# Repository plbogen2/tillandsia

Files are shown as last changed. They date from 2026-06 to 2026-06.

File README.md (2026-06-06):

# Aeropress Cleaners (ADCR & AMFC)

This repository contains two 3D-printable, office-desk-friendly cleaning tools for the **AeroPress** coffee maker, designed to clean coffee grounds directly over a trash can:
1.  **Plunger Wiper Ring (ADCR)**: Sweeps coffee grounds off the rubber plunger seal face using a spring-returned pivoted squeegee.
2.  **Metal Filter Cleaner (AMFC)**: Wipes grounds off both sides of a circular metal mesh filter using a clamped double-sided squeegee envelope.

Both tools are designed to print completely **support-free** and assemble using standard Prusa-style **M3 metal screws** and a **harvested Mounjaro pen spring**.

---

## 1. Plunger Wiper Ring (ADCR)

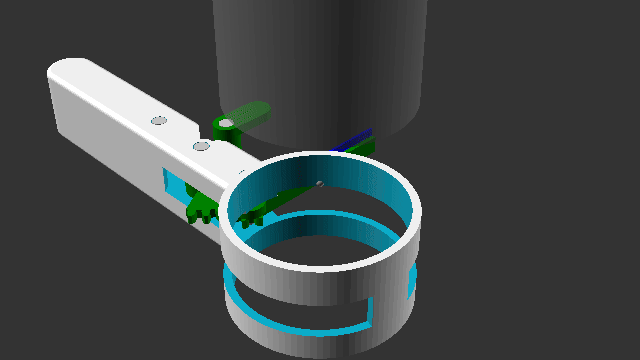
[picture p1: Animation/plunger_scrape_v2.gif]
Plunger Scraping Action


### How It Works:
*   Slide the ring collar over the Aeropress plunger seal until it sits flush against the internal stop ledge.
*   Push the thumb lever to compress the spring and sweep the flexible blade across the plunger face.
*   Release the lever. The vertical Mounjaro pen spring pops the arm back to the park position.
*   Coffee grounds fall out the open bottom of the ring.

### Bill of Materials & Print Guide:
*   **M3x12mm Screw** (x1): Functions as the metal hinge pivot shaft. Threads directly into the top knuckle plastic.
*   **Mounjaro Pen Spring** (x1): Harvested from a spent injection pen (approx. 8mm OD, 40mm length).
*   **ring.stl** (Rigid): Print **upside-down (top rim on bed)**, no supports.
*   **wiper.stl** (Rigid): Print flat on bed.
*   **blade.stl** (Flexible TPU): Print flat on bed.

---

## 2. Metal Filter Cleaner (AMFC)

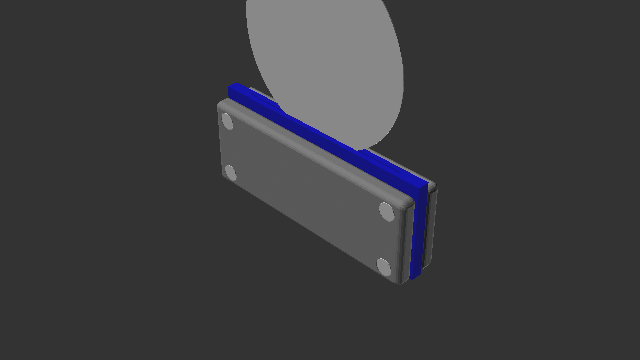
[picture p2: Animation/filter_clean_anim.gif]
Filter Cleaning Action


### How It Works:
*   Hold the filter cleaner vertically over a trash can.
*   Push your circular metal mesh filter ($62\text{mm}$) down into the top chamfered funnel guide.
*   Slide the filter all the way through the channel. Dual TPU squeegee blades scrape both faces of the filter at the same time.
*   Cleaned filter slides out the bottom, while grounds fall straight down into the trash.

### Bill of Materials & Print Guide:
*   **M3x12mm Screws** (x4): Securely clamp the front and back halves together.
*   **filter_front.stl** (Rigid): Contains M3 clearance screw holes. Print flat, mating face on bed.
*   **filter_back.stl** (Rigid): Contains M3 tap holes. Print flat, mating face on bed.
*   **filter_blade.stl** (Flexible TPU, x2): Print flat. Simple rectangular squeegee sheets ($55\text{mm} \times 15\text{mm} \times 1.5\text{mm}$).

---

## Assembly Instructions

### Plunger Ring:
1.  Insert the flexible **blade** into the slot on the **wiper** arm (starts 8mm from pivot).
2.  Press-fit the Mounjaro pen spring onto the stationary **Ring Post peg** and the moving **Lever Post peg**.
3.  Align the wiper knuckle with the ring knuckles and insert your **M3x12mm screw** from the bottom. Tighten until the head is flush inside the bottom recess.

### Filter Cleaner:
1.  Place the two flat TPU **filter_blade** sheets into the recesses of the **filter_front** and **filter_back** halves.
2.  Press the front and back halves together (alignment tracks will match).
3.  Insert **four M3x12mm screws** from the front clearance side and screw them securely into the back tap holes to clamp the blades flat.

---

## Customization in OpenSCAD
Each project has its own parametric model:
*   `aeropress_cleaner.scad`: Customizable plunger diameters (`plunger_di`), wall thickness, and M3 clearance fits.
*   `filter_cleaner.scad`: Customizable filter diameters (`filter_di`), filter thickness, and blade clearances.

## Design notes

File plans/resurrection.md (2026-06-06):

# Jetski Project Resurrection State: Aeropress Cleaners (ADCR & AMFC)

Use this file to instantly restore context, design knowledge, and execution progress when starting a new session or switching development machines.

---

## 1. Project Goals
Design and print support-free, office-desk-friendly cleaning tools for the **AeroPress** coffee maker:
1.  **Plunger Wiper Ring (ADCR)**: Cleans the rubber plunger seal face (diameter **57.2mm**, dome: **3.5mm**) using a spring-returned pivoted squeegee. Uses a harvested Mounjaro pen spring and a single M3x12mm screw.
2.  **Metal Filter Cleaner (AMFC)**: Wipes grounds off both sides of a circular metal mesh filter (diameter **62.0mm**, thickness **0.3mm**) using a clamped double-sided squeegee envelope. Uses four M3x12mm screws.

---

## 2. Selected Architectures

### Plunger Wiper Ring (ADCR)
*   **Ring Body (Rigid)**: A 35mm tall collar (ID 57.5mm) with an internal stop ledge (ID 53.0mm) at $z = 15.0 \to 18.0\text{ mm}$ and a $10.0\text{ mm}$ tall wall slot ($z = -8.0 \to +2.0\text{ mm}$) covering $330^\circ$.
*   **Clevis Hinge**: Double shear knuckles at $z = -12.0 \to -8.0\text{ mm}$ (lower) and $z = -4.0 \to 0.0\text{ mm}$ (upper). Secures via an M3x12mm screw.
*   **Wiper Arm & Blade**: A $65\text{mm}$ lever with a $57\text{mm}$ TPU blade starting at local $x = 8.0\text{ mm}$ to clear the hinge.
*   **Spring Return**: Mounjaro pen spring captured vertically on $6\text{mm}$ pegs on the ring post and lever post.

### Metal Filter Cleaner (AMFC)
*   **Front Half (Rigid)**: Contains a recessed track (depth $0.5\text{mm}$, width $62.5\text{mm}$) for the filter path, a pocket ($55.2\text{mm} \times 15.2\text{mm} \times 1.5\text{mm}$) for one TPU blade, and four M3 screw clearance holes (diameter $3.3\text{mm}$) with countersunk recesses.
*   **Back Half (Rigid)**: Mirrored copy of the front half, but with M3 tap holes (diameter $2.8\text{mm}$) to screw the clamp halves together.
*   **Wiper Blades (Flexible TPU, x2)**: Flat rectangular sheets ($55.0\text{mm} \times 15.0\text{mm} \times 1.5\text{mm}$) clamped between the halves, with tips extending into the channel to scrape both sides of the filter mesh.

---

## 3. Parametric Design Values

### Plunger Ring (`aeropress_cleaner.scad`)
*   `plunger_di = 57.2;` (AeroPress plunger seal diameter)
*   `wall_thickness = 3.0;` (Ring shell thickness)
*   `pivot_x = -35.0; pivot_y = 0.0;` (Pivot position)
*   `screw_tap_d = 2.8;` (Upper knuckle tap bore for M3 screw)
*   `screw_clearance_d = 3.3;` (Lower/arm knuckle clearance bore)
*   `ring_post_x = -55.0; ring_post_y = -12.0;` (Stationary spring post position)
*   `spring_peg_d = 6.0;` (Peg diameter for spring mounting)

### Filter Cleaner (`filter_cleaner.scad`)
*   `filter_di = 62.0;` (Metal filter mesh diameter)
*   `filter_thickness = 0.3;` (Filter thickness)
*   `blade_w = 55.0; blade_h = 15.0; blade_t = 1.5;` (TPU sheet dimensions)
*   `frame_w = 78.0; frame_h = 30.0; frame_t = 7.0;` (Half-clamp block dimensions)
*   `screw_x_offset = 34.0; screw_z_offset = 10.0;` (M3 clamping screw grid positions)

---

## 4. Repository File Index
*   [`aeropress_cleaner.scad`](file:///usr/local/google/home/plbogen/github/tillandsia/aeropress_cleaner.scad): Plunger cleaner CAD model.
*   [`filter_cleaner.scad`](file:///usr/local/google/home/plbogen/github/tillandsia/filter_cleaner.scad): Metal filter cleaner CAD model.
*   [`export.ps1`](file:///usr/local/google/home/plbogen/github/tillandsia/export.ps1): PowerShell script that exports all STLs and renders the plunger and filter animations (for Windows and CI).
*   [`export.sh`](file:///usr/local/google/home/plbogen/github/tillandsia/export.sh): Bash shell script that does the same (for native gLinux/Linux execution).
*   [`README.md`](file:///usr/local/google/home/plbogen/github/tillandsia/README.md): Landing page documentation detailing assembly and print guidelines.

---

## 5. Printing & Slicing
*   **Plunger Cleaner**:
    *   `STLs/ring.stl` -> PETG/PLA, print **upside-down (top rim on bed)**. Support-free.
    *   `STLs/wiper.stl` -> PETG/PLA, print flat.
    *   `STLs/blade.stl` -> TPU, print flat.
*   **Filter Cleaner**:
    *   `STLs/filter_front.stl` -> PETG/PLA, print flat, mating face on bed.
    *   `STLs/filter_back.stl` -> PETG/PLA, print flat, mating face on bed.
    *   `STLs/filter_blade.stl` (x2) -> TPU, print flat.

---

## 6. Assembly Steps

### Plunger Ring:
1.  Insert the flexible `blade` into the `wiper` arm's slot.
2.  Press-fit the Mounjaro pen spring onto the stationary **Ring Post peg** and the moving **Lever Post peg**.
3.  Align the wiper arm knuckle inside the slot between the ring's upper and lower knuckles.
4.  Insert an **M3x12mm screw** from the bottom and screw it tight into the upper knuckle.

### Filter Cleaner:
1.  Place the two TPU **filter_blade** sheets into the recesses of the **filter_front** and **filter_back** halves.
2.  Press the front and back halves together.
3.  Insert **four M3x12mm screws** from the front and screw them securely into the back tap holes to clamp the blades flat.

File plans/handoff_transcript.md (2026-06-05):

# Design Handoff: Aeropress Desk Cleaning Funnel (ADCF)

This document records the design rationale, parameters, alternatives, and technical specifications for the Aeropress Desk Cleaning Funnel (ADCF) created for the `tillandsia` repository.

## 1. Problem Statement
The user has an Aeropress with a flow control cap, a metal filter, and a paper filter. In an office setting equipped only with a kettle and a trash can (no immediate access to a sink or running water), the user needs to clean coffee grounds off:
1. **The Plunger Seal**: The convex face and cylindrical outer walls of the rubber seal.
2. **The Metal Filter**: The flat faces of the stainless steel filter disc.

The goal is to design a 3D-printable tool that cleans both components using dry scraping, funneling all coffee grounds directly into a trash can without water or mess.

---

## 2. Alternatives Considered

### Alternative A: Dual-Ended Scraper Wand
*   **Description**: A compact handheld wand with a curved scraper on one end and a split-jaw squeegee clamp on the other.
*   **Pros**: Very fast print, low material usage, small footprint.
*   **Cons**: Requiring manual handling near coffee grounds; leaves the wand itself covered in wet grounds which would then require wiping/washing.

### Alternative B: Desk-Side Rinse & Scrape Station
*   **Description**: A small container holding a splash of hot water from the kettle to dip/loosen grounds, alongside squeegee slots.
*   **Pros**: Dissolves oils and removes fine particles better than dry scraping.
*   **Cons**: Introduces liquid waste disposal problems in an office desk setting (requires emptying a cup of muddy coffee water).

### Alternative C: Unified Cleaning Funnel (Selected)
*   **Description**: A handheld funnel with a handle and a side-mounting slot. Pushing the plunger down cleans it; sliding the metal filter through the slot cleans both sides. Grounds fall directly down into the trash.
*   **Pros**: Complete containment of waste, hands-free scraping directly into the trash, modular and easy to print without supports.

---

## 3. Selected Design: Aeropress Desk Cleaning Funnel (ADCF)

The design is modular to allow printing on single-extruder 3D printers using two different materials:
1.  **Funnel Body (Rigid - PETG/PLA)**: Holds the components and handles the waste.
2.  **Plunger Squeegee Insert (Flexible PLA)**: Snaps into the top of the funnel to scrape the plunger.
3.  **Filter Squeegee halves (Flexible PLA - print 2)**: Stack inside the side pocket to scrape the metal filter.

### Key Design Highlights:
*   **Support-Free Printing**: The funnel wall angles, the vertical handle loop, the pocket support gusset, and the internal shoulders are all designed at or under 45 degrees relative to the vertical axis when printed bottom-up. No support material is required.
*   **Unified Path**: The plunger moves downwards through a circular squeegee lip that pushes grounds down off the seal. At the bottom, a curved blade matching the dome of the plunger seal wipes the face clean when twisted.
*   **Filter Stability**: A slot in the opposite inner wall of the funnel guides and stabilizes the far edge of the metal filter as it is pushed through the scraper block, preventing the thin metal disc from bending.
*   **No-Bridge Slot**: The filter scraper block is split horizontally into two identical halves, enabling flat printing on the bed to prevent slot sag and ensure pristine scraping lips.

---

## 4. File Structure & CAD Model
The CAD model has been saved to the repository at:
*   `[aeropress_cleaner.scad](file:///usr/local/google/home/plbogen/github/tillandsia/aeropress_cleaner.scad)`

The file contains customizer parameters allowing adjustment of:
*   `plunger_di` (default 57.2mm)
*   `plunger_dome_h` (default 3.5mm)
*   `filter_di` (default 62.0mm)
*   `filter_thickness` (default 0.3mm)
*   `clearance` (default 0.2mm)
*   `wall_thickness` (default 2.4mm)
*   `flex_wall` (default 2.0mm)

You can select which part to export (`all`, `funnel`, `plunger_insert`, or `filter_insert`) using the `part` variable.

---

## 5. Next Steps
1.  Open `aeropress_cleaner.scad` in OpenSCAD.
2.  Render and export the STL for `part = "funnel"` in PETG or PLA.
3.  Render and export the STL for `part = "plunger_insert"` in Flexible PLA.
4.  Render and export the STL for `part = "filter_insert"` in Flexible PLA (print two copies).
5.  Assemble by dropping the plunger insert into the top of the funnel (lining up the keys) and sliding the two filter insert halves into the side pocket.

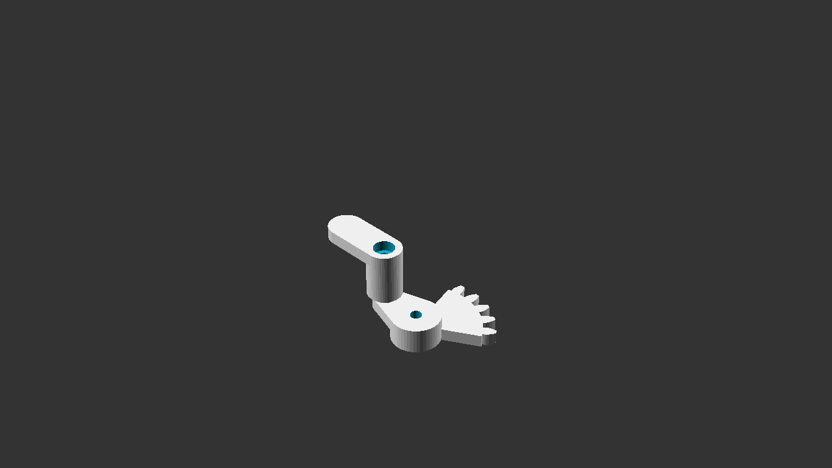
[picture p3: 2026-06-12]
PNGs/trigger.png

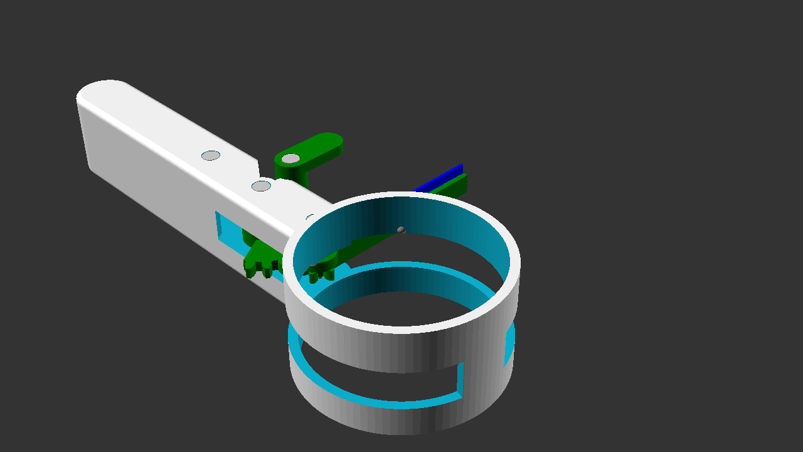
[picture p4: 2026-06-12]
PNGs/preview_v2.png

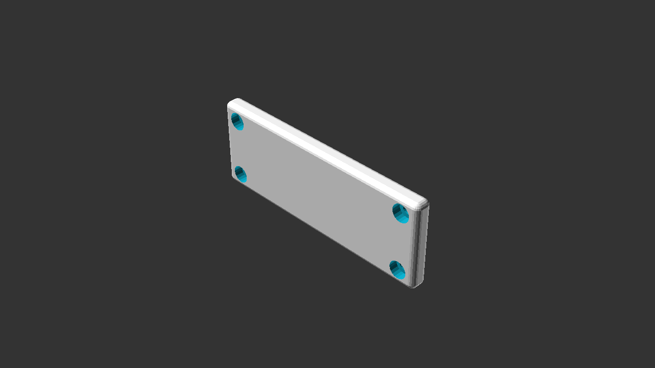
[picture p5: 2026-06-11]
PNGs/filter_front.png

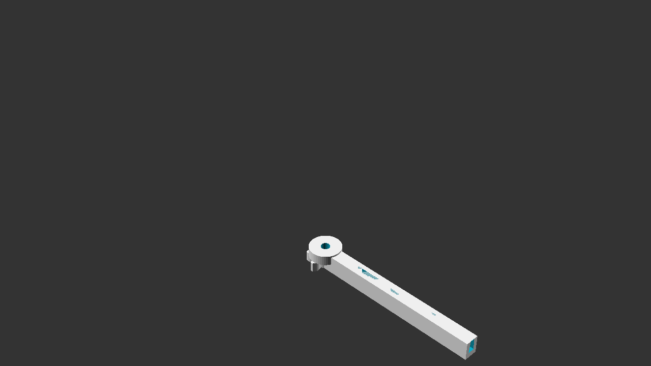
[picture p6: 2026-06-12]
PNGs/wiper.png

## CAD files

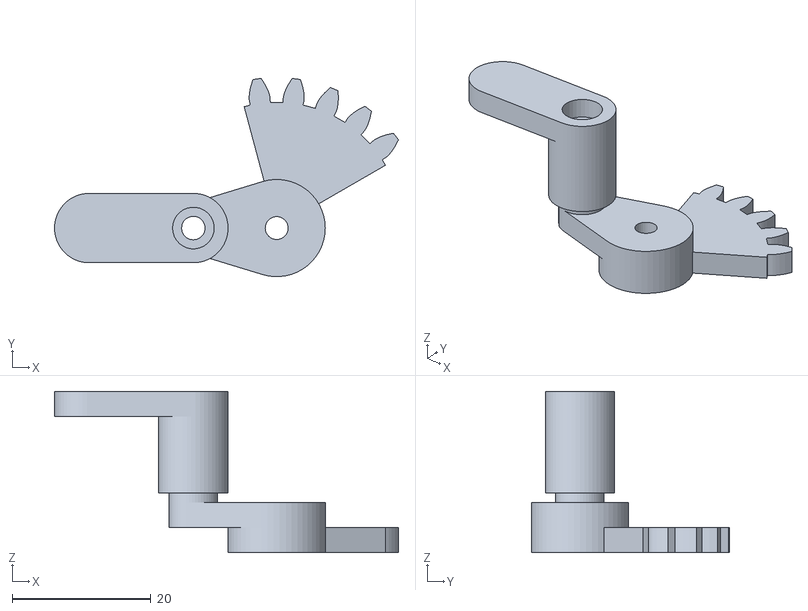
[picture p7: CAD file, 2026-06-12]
STLs/trigger.stl
49.5 x 28.5 x 23.2

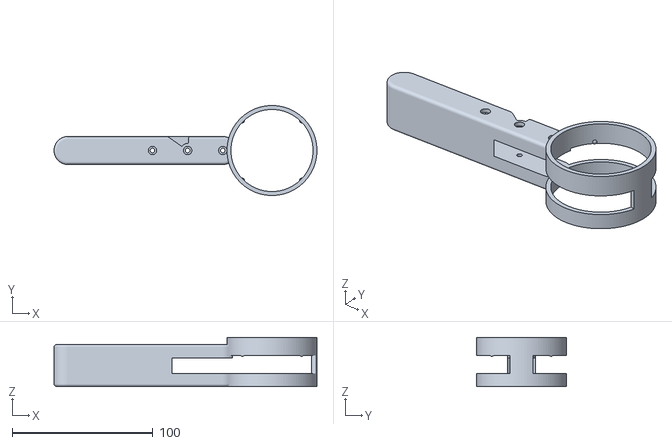
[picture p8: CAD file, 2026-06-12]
STLs/ring.stl
187.0 x 64.0 x 35.0

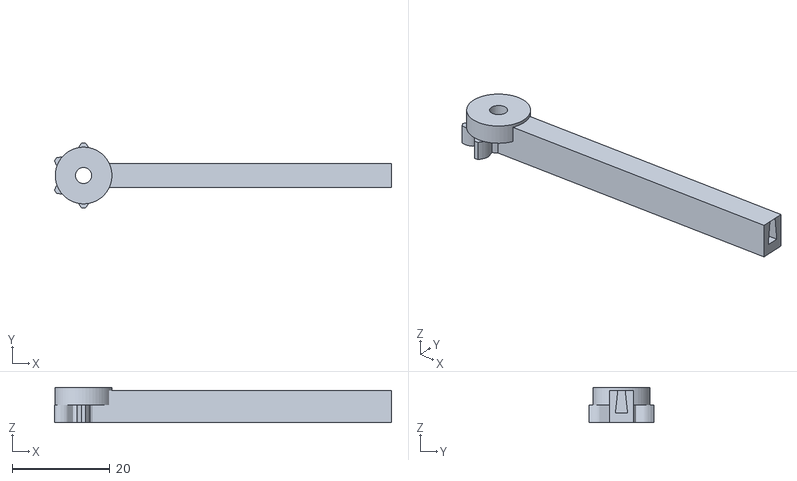
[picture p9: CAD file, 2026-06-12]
STLs/wiper.stl
69.0 x 13.3 x 7.20

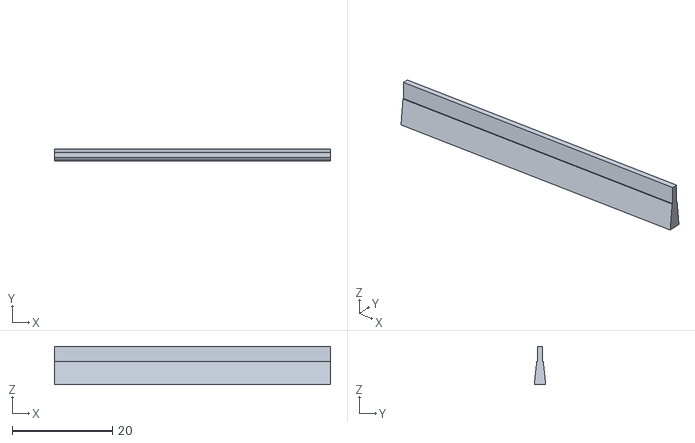
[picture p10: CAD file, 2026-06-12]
STLs/blade.stl
55.0 x 2.30 x 7.60

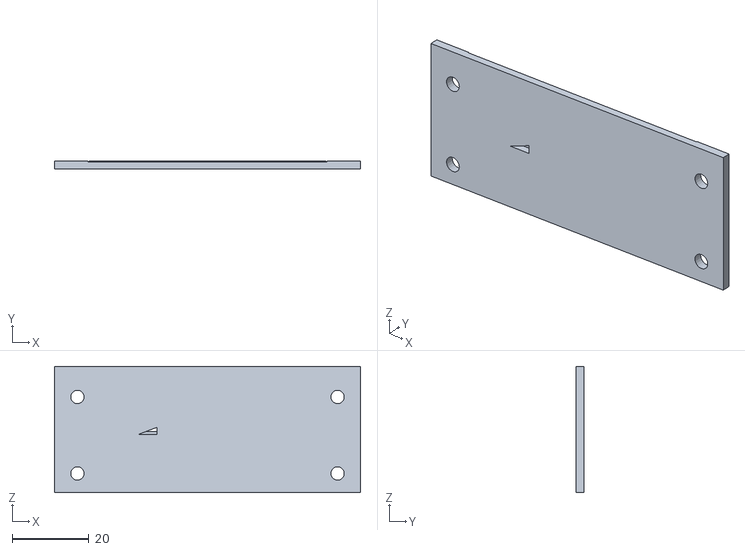
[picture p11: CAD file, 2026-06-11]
STLs/filter_blade.stl
80.0 x 2.00 x 33.0

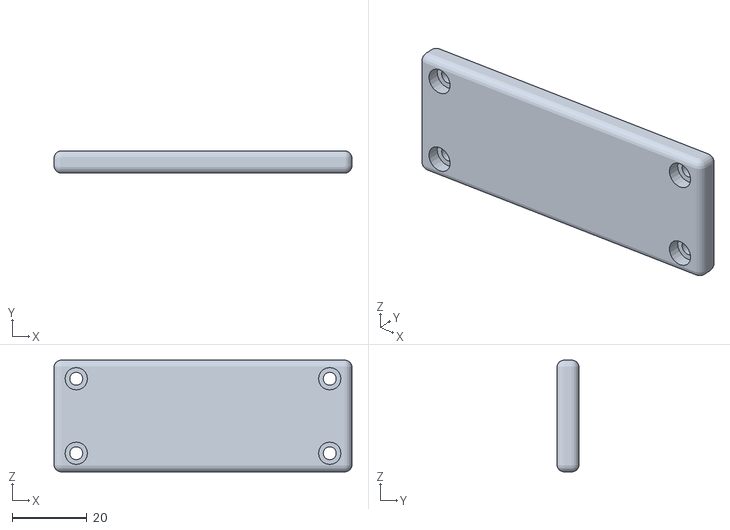
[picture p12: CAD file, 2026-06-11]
STLs/filter_front.stl
80.0 x 5.95 x 30.0

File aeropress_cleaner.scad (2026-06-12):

// OpenSCAD Model for Aeropress Plunger Wiper Ring (ADCR)
// Simplified 2-Part Mechanical System with Shroud and M3 Metal Pivot Screw:
// 1. Ring Body (Rigid): 35mm tall collar with 330-degree slot and internal stop ledge.
// 2. Wiper Arm (Rigid): Long pivoted lever (65mm) that completely crosses the plunger.
// 3. Wiper Blade (Flexible): 57mm TPU blade pointing upwards, starts 8mm from pivot.

use <MCAD/involute_gears.scad>

// --- PART SELECTOR ---
part = "all"; // [all: Visual Assembly, ring: Ring Body (Rigid), wiper: Wiper Arm (Rigid), trigger: Trigger Lever (Rigid), blade: Wiper Blade (Flexible)]

// --- CUSTOMIZABLE PARAMETERS ---
plunger_di = 58.0;
plunger_dome_h = 3.5;
right_handed = false; // Set to true for right-handed version, false for left-handed

// --- ADVANCED PARAMETERS ---
wall_thickness = 3.0; // thick walls for robust ring
clearance = 0.2;

// Hinge/Pivot geometry (M3 Metal Screw Pivot)
pivot_x = -35.0;
pivot_y = 0.0;
trigger_pivot_x = -60.0;
trigger_pivot_y = 0.0;

screw_tap_d = 2.8;     // M3 threads tap directly into plastic
screw_clearance_d = 3.3; // loose fit for smooth pivot rotation
screw_head_d = 6.0;    // recess for M3 socket head cap screw
screw_head_h = 2.5;

// Handle and Spring peg positions
stationary_handle_x = -145.0;
stationary_handle_y = 0.0;
spring_peg_d = 3.0; // fits inside 4mm ID spring
handle_roundover = 2.0; // radius of roundover on handle edges

// --- ANIMATION CONTROLS ---
animate = false;
time_t = undef;
t_val = (time_t != undef) ? time_t : $t;

// Wiper Angle Animation:
// t = 0.0 -> 0.2: Wiper parks at +90 degrees (idle, top)
// t = 0.2 -> 0.5: Wiper sweeps clockwise to -90 degrees (compressing spring)
// t = 0.5 -> 0.8: Wiper returns counter-clockwise to +90 degrees
wiper_angle = 
    (t_val < 0.2) ? 90 :
    (t_val < 0.5) ? 90 - ((t_val - 0.2) / 0.3) * 180 :
    (t_val < 0.8) ? -90 + ((t_val - 0.5) / 0.3) * 180 :
    90;

// Trigger Angle Animation: Squeezes counter-clockwise from -90 -> -45 linked to wiper (ratio 4:1)
trigger_angle = -90.0 - (wiper_angle - 90.0) / 4.0;


// Plunger insertion animation
plunger_z = 
    (t_val < 0.1) ? 60 - (t_val/0.1)*60 :
    (t_val < 0.8) ? 0.0 :
    ((t_val - 0.8)/0.2)*60;

module directional_layout() {
    if (right_handed) {
        mirror([1, 0, 0]) children();
    } else {
        children();
    }
}

if (part == "all") {
    directional_layout() assembly();
} else if (part == "ring") {
    directional_layout() ring_body();
} else if (part == "wiper") {
    directional_layout() wiper_arm();
} else if (part == "trigger") {
    directional_layout() trigger_lever();
} else if (part == "blade") {
    directional_layout() wiper_blade();
}

module assembly() {
    // 1. Ring Body (Rigid)
    ring_body();
    
    // 2. Wiper Arm & Blade (Pivot A)
    translate([pivot_x, pivot_y, 0.0]) {
        rotate([0, 0, wiper_angle]) {
            color("green") wiper_arm();
            color("blue") wiper_blade();
        }
    }
    
    // 3. Trigger Lever (Pivot B)
    translate([trigger_pivot_x, trigger_pivot_y, 0.0]) {
        rotate([0, 0, trigger_angle]) {
            color("green") trigger_lever();
            // Mock M3x20 screw for trigger spring peg (translated to counterbore shoulder Z=16.6)
            translate([-12.0, 0.0, 16.6])
                rotate([180, 0, 0])
                    mock_m3_screw(len = 20.0);
        }
    }
    
    // 4. M3 Metal Pivot Screws (Pivot A & B)
    // Translated to counterbore shoulder (Z = 15.0 - 3.0 = 12.0)
    translate([pivot_x, pivot_y, 12.0])
        rotate([180, 0, 0])
            mock_m3_screw(len = 30.0);
    translate([trigger_pivot_x, trigger_pivot_y, 12.0])
        rotate([180, 0, 0])
            mock_m3_screw(len = 30.0);
            
    // 4a. Mock M3x30 screw for casing spring peg (Through-screw, head at top Z=12.0)
    translate([-85.0, 0.0, 12.0])
        rotate([180, 0, 0])
            mock_m3_screw(len = 30.0);
            
    // 5. Mock Plunger (Animated)
    if (animate || t_val > 0) {
        translate([0, 0, plunger_z])
            mock_plunger();
    }
    
    // 6. Mock Spring (Animated compression between pegs, global z = -4.2)
    trigger_peg_x = trigger_pivot_x + 12.0 * cos(trigger_angle + 180.0);
    trigger_peg_y = trigger_pivot_y + 12.0 * sin(trigger_angle + 180.0);
    
    stationary_peg_x = -85.0;
    stationary_peg_y = 0.0;
    
    dx = trigger_peg_x - stationary_peg_x;
    dy = trigger_peg_y - stationary_peg_y;
    dist = sqrt(dx*dx + dy*dy);
    angle = atan2(dy, dx);
    
    color("red")
        translate([stationary_peg_x, stationary_peg_y, 0.0])
            rotate([0, 0, angle])
                rotate([0, 90, 0])
                    cylinder(d = 10.0, h = dist, $fn=20);
}

module ring_body() {
    difference() {
        // UNION of all positive geometry
        union() {
            // 1. Ring Wall (with Slot cut out of it)
            difference() {
                // Main ring cylinder (height 35mm, from z = -15 to +20)
                translate([0, 0, -15.0])
                    cylinder(d = plunger_di + 2 * wall_thickness, h = 35.0, $fn = 100);
                
                // Horizontal Slot in ring wall for arm/blade to sweep (Z span: z = -5.5 -> +7.0, height 12.5mm)
                translate([0, 0, -5.5]) {
                    intersection() {
                        difference() {
                            cylinder(d = plunger_di + 2*wall_thickness + 5.0, h = 12.5, $fn=100);
                            cylinder(d = plunger_di - 2.0, h = 14.0, center=true, $fn=100);
                        }
                        linear_extrude(height = 12.5) {
                            polygon([
                                [0.0, 0.0],
                                [75.0 * cos(15.0), 75.0 * sin(15.0)],
                                [75.0 * cos(90.0), 75.0 * sin(90.0)],
                                [75.0 * cos(180.0), 75.0 * sin(180.0)],
                                [75.0 * cos(270.0), 75.0 * sin(270.0)],
                                [75.0 * cos(345.0), 75.0 * sin(345.0)]
                            ]);
                        }
                    }
                }
            }
            
            // 2. Straight Tuning-Fork Handle Casing (z = -15.0 -> 15.0, H = 30mm)
            // A simple straight flat bar running from Pivot A to the grip end.
            hull() {
                translate([pivot_x, pivot_y, 0.0])
                    rounded_cylinder(d = 20.0, h = 30.0, r = handle_roundover, center = true);
                translate([trigger_pivot_x, trigger_pivot_y, 0.0])
                    rounded_cylinder(d = 20.0, h = 30.0, r = handle_roundover, center = true);
                translate([stationary_handle_x, 0.0, 0.0])
                    rounded_cylinder(d = 20.0, h = 30.0, r = handle_roundover, center = true);
            }
        }
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

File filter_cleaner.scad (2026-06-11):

// OpenSCAD Model for Aeropress Metal Filter Cleaner (AMFC)
// Clamped 3-Piece Design using standard M3 Screws:
// 1. Front Half (Rigid): Holds front TPU blade, contains M3 clearance holes.
// 2. Back Half (Rigid): Holds back TPU blade, contains M3 tap holes.
// 3. Wiper Blades (Flexible, x2): Simple flat TPU sheets (55mm x 15mm x 1.5mm).

// --- PART SELECTOR ---
part = "all"; // [all: Visual Assembly, front: Front Half (Rigid), back: Back Half (Rigid), blade: Flex PLA Insert (Flexible)]

// --- PARAMETERS ---
filter_di = 62.0;       // Standard metal filter diameter
filter_thickness = 0.3; // Metal filter thickness
wall_thickness = 3.0;   // Outer wall shell thickness

// Frame & Flex dimensions
frame_w = filter_di + 2 * wall_thickness + 12.0; // 80mm total width (widened for corner screw clearance)
frame_h = 30.0;                                  // 30mm vertical height
frame_t = 6.0;                                   // 6mm thick rigid backing plates (thickened to fit 12mm screws)
flex_t = 2.0;                                    // 2mm thick flex PLA inserts
flex_h = frame_h + 3.0;                          // 33mm flex plate height (extends 3mm ONLY at top)

// Dado (Filter Channel) dimensions
dado_w = filter_di + 0.5; // 62.5mm width (0.5mm clearance)
dado_d = 0.15;            // 0.15mm depth per side (0.3mm total channel gap)

// Scraping Ridge dimensions
ridge_w = 62.0; // 62mm wide (covers filter mesh area)
ridge_h = 0.15; // 0.15mm height above dado bottom (reaches split plane)
ridge_t = 2.0;  // 2.0mm vertical width of the ridge

// M3 Screw spacing
screw_x_offset = 34.0;              // 34mm from center (kept at 34 to clear dado)
screw_z_offset = 10.0;              // screws at z = -10 and +10

// M3 Hex Nut dimensions (DIN 934)
hex_nut_w = 5.8; // 5.8mm flat-to-flat pocket width (5.5mm nut + 0.3mm tolerance for snug fit)
hex_nut_d = 3.0; // 3.0mm pocket depth (2.4mm nut + 0.6mm tolerance)

// --- ANIMATION CONTROLS ---
animate = false;
time_t = undef;
t_val = (time_t != undef) ? time_t : $t;

// Filter position animation (passes through from top to bottom)
// t = 0.2 -> 0.8: filter slides from z = 45 (above) to z = -45 (below)
filter_z = 
    (t_val < 0.2) ? 45.0 :
    (t_val < 0.8) ? 45.0 - ((t_val - 0.2) / 0.6) * 90.0 :
    -45.0;

if (part == "all") {
    assembly();
} else if (part == "front") {
    front_half();
} else if (part == "back") {
    back_half();
} else if (part == "blade") {
    flex_plate();
}

module assembly() {
    // 1. Front Half (Rigid, transparent in assembly to see inside)
    color([0.7, 0.7, 0.7, 0.5])
        translate([0, -flex_t, 0])
            front_half();
            
    // 2. Front Flex Plate (Flex PLA, transparent blue, grooved)
    color([0.0, 0.0, 1.0, 0.6])
        translate([0, 0, 0])
            flex_plate();
            
    // 3. Back Flex Plate (Flex PLA, transparent blue, mirrored to face front)
    color([0.0, 0.0, 1.0, 0.6])
        mirror([0, 1, 0])
            flex_plate();
            
    // 4. Back Half (Rigid, solid)
    color("gray")
        translate([0, flex_t, 0])
            back_half();
                
    // 5. Mock M3 Screws (x4)
    // Shaft heads are on the front surface (y = -flex_t - frame_t)
    for (x = [-screw_x_offset, screw_x_offset]) {
        for (z = [-screw_z_offset, screw_z_offset]) {
            translate([x, -flex_t - frame_t, z])
                rotate([-90, 0, 0])
                    mock_m3_screw(len = 12.0);
        }
    }
    
    // 6. Mock Metal Filter (Animated)
    if (animate || t_val > 0) {
        translate([0, -filter_thickness/2, filter_z])
            rotate([90, 0, 0])
                color("silver")
                    cylinder(d = filter_di, h = filter_thickness, center = true, $fn = 100);
    }
}

module rounded_box(w, t, h, r) {
    // Generates a rounded box of width w, thickness t, height h, with all edges rounded by radius r.
    // The box extends in +Y direction from y=0 to t.
    // Centered in X and Z.
    $fn = 20;
    hull() {
        for (x = [-w/2 + r, w/2 - r]) {
            for (y = [r, t - r]) {
                for (z = [-h/2 + r, h/2 - r]) {
                    translate([x, y, z])
                        sphere(r = r);
                }
            }
        }
    }
}

module front_half() {
    // Rounded front clamp plate.
    // Local coordinate origin [0,0,0] is on the mating plane.
    // Plate extends in the -Y direction from y = 0 to -frame_t.
    difference() {
        // Main rounded block (translated to extend in -Y)
        translate([0, -frame_t, 0])
            rounded_box(frame_w, frame_t, frame_h, 2.0);
            
        // M3 Screw Clearance Holes with Counterbores
        for (x = [-screw_x_offset, screw_x_offset]) {
            for (z = [-screw_z_offset, screw_z_offset]) {
                // Shaft clearance (D=3.5)
                translate([x, 1.0, z])
                    rotate([90, 0, 0])
                        cylinder(d = 3.5, h = frame_t + 2.0, $fn = 20);
                // Counterbore recess (D=6.0, depth 3.0)
                translate([x, -frame_t + 3.0, z])
                    rotate([90, 0, 0])
                        cylinder(d = 6.0, h = 4.1, $fn = 20);
            }
        }
    }
}

module back_half() {
    // Simple flat back clamp plate.
    // Local coordinate origin [0,0,0] is on the mating plane.
    // Plate extends in the +Y direction from y = 0 to frame_t.
    difference() {
        // Main rounded block
        rounded_box(frame_w, frame_t, frame_h, 2.0);
            
        // M3 Screw Clearance Holes (D=3.5) and Hex Nut Pockets
        for (x = [-screw_x_offset, screw_x_offset]) {
            for (z = [-screw_z_offset, screw_z_offset]) {
                // Clearance shaft
                translate([x, frame_t + 1.0, z])
                    rotate([90, 0, 0])
                        cylinder(d = 3.5, h = frame_t + 2.0, $fn = 20);
                
                // Hex nut pocket (D=6.0 flat-to-flat, depth=3.0) cut from the rear face (y = frame_t)
                translate([x, frame_t + 0.1, z])
                    rotate([90, 0, 0])
                        rotate([0, 0, 30])
                            cylinder(d = hex_nut_w / cos(30), h = hex_nut_d + 0.2, $fn = 6);
            }
        }
    }
}

module flex_plate() {
    // Symmetric flexible clamping plate with dado (channel) and scraping ridge.
    // Local coordinate origin [0,0,0] is on the mating plane.
    // Base plate extends in the -Y direction from y = 0 to -flex_t.
    difference() {
        union() {
            // 1. Base plate with vertical channel and funnel cut out
            difference() {
                // Base block (extended only at top: Z = -15 -> 18)
                translate([-frame_w/2, -flex_t, -frame_h/2])
                    cube([frame_w, flex_t, flex_h]);
                // Vertical Dado (channel of depth dado_d = 0.15, Z = -16 -> 19)
                translate([-dado_w/2, -dado_d - 0.05, -frame_h/2 - 1.0])
                    cube([dado_w, dado_d + 0.1, flex_h + 2.0]);
                // Entry Funnel (Top) - slants the channel back to the plate rear face (Z = 13 -> 18.1)
                translate([-dado_w/2, 0, 0])
                    rotate([90, 90, 0]) // Fixed rotation
                        linear_extrude(height = dado_w)
                            polygon([
                                [-dado_d, frame_h/2 - 2.0], // Starts inside frame (Z = 13)
                                [-flex_t - 0.1, frame_h/2 + 3.1], // Ends at top of extended flex (Z = 18.1)
                                [-dado_d, frame_h/2 + 3.1]
                            ]);
            }
            // 2. Scraping Ridge (added back on top of the channel surface)
            // Starts at y = -dado_d (-0.15), extends by ridge_h (0.15) to y = 0.0 (mating plane)
            translate([-ridge_w/2, -dado_d, -ridge_t/2])
                cube([ridge_w, ridge_h, ridge_t]);
        }
        // 3. M3 Screw Clearance Holes (D=3.5)
        for (x = [-screw_x_offset, screw_x_offset]) {
            for (z = [-screw_z_offset, screw_z_offset]) {
                translate([x, 1.0, z])
                    rotate([90, 0, 0])
                        cylinder(d = 3.5, h = flex_t + 2.0, $fn = 20);
            }
        }
    }
}

module mock_m3_screw(len = 12.0) {
    color("silver") {
        // Cap Head (D=5.5, H=3.0)
        cylinder(d = 5.5, h = 3.0, $fn = 20);
        // Shaft (D=3.0, H=len)
        translate([0, 0, 3.0])
            cylinder(d = 3.0, h = len, $fn = 20);
    }
}

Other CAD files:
STLs/filter_back.stl
MCAD/involute_gears.scad

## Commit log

2026-06-05 Initial commit: Aeropress Desk Cleaning Funnel (ADCF)
    [aeropress_cleaner.scad]
2026-06-05 feat: Add GitHub Actions automation for OpenSCAD STL and PNG export
2026-06-05 chore: auto-generate STLs and PNGs [skip ci]
    [filter_insert.stl, funnel.stl, plunger_insert.stl]
2026-06-05 feat: Add animation support to OpenSCAD file and update GitHub Actions to render GIF
    [aeropress_cleaner.scad]
2026-06-05 docs: Add README.md with embedded animation and printing instructions
2026-06-05 fix: Replace OpenSCAD CLI --animate with manual frame loop in export.ps1
2026-06-05 fix: Resolve static animation using time_t, thicken filter scraper lips, and make handle a rounded ergonomic D-shape
    [aeropress_cleaner.scad]
2026-06-05 chore: auto-generate STLs, PNGs, and GIF [skip ci]
    [filter_insert.stl, funnel.stl]
2026-06-05 feat: Add 360-degree camera rotation to the output animation GIF
2026-06-05 fix: Rotate keyways 90 deg, shift filter slot to 47.5, and use a drawer-style pocket to prevent collision and increase robustness
    [aeropress_cleaner.scad]
2026-06-05 fix: Centered filter block locally for clean rotation, added beveled pocket profile for smooth outer transitions
    [aeropress_cleaner.scad]
2026-06-05 docs: Link standard plunger and filter dimensions to online sources in README
2026-06-05 fix: Redesign metal filter scraper to slide vertically (upwards from bottom) and integrate beveled vertical column housing
    [aeropress_cleaner.scad]
2026-06-05 fix: Redesign to separate 2-part architecture (Simple Rigid Funnel and Handheld Flexible Scraper with living hinge)
    [aeropress_cleaner.scad, filter_insert.stl, plunger_insert.stl]
2026-06-05 docs: Update README to show two separate animations (plunger and filter cleaning) in a carousel, and reflect the 2-part print specifications
    [aeropress_cleaner.scad]
2026-06-05 fix: Solve shell quote escaping by converting anim_mode to integers, update README layouts to use tables, check-in resurrection state file
    [aeropress_cleaner.scad]
2026-06-05 fix: Redesign plunger scraper to be a shallow flexible cup for full-face squeegeeing, fix Z-rotation flip to align scraper jaws in GIFs
    [aeropress_cleaner.scad]
2026-06-05 feat: Pivot to mechanical spring-loaded pivoted wiper design for full plunger-face cleaning, using harvested Mounjaro pen spring
    [aeropress_cleaner.scad, scraper.stl]
2026-06-05 feat: Simplify design to Plunger Wiper Ring (ADCR) without funnel, removing wall slots and mounting wiper at open bottom
    [aeropress_cleaner.scad, funnel.stl]
2026-06-05 fix: Adjust vertical assembly translations and wiper blade height to correct cleaning arm placement
    [aeropress_cleaner.scad]
2026-06-06 feat: Redesign to include ring shroud, horizontal wall slot, and dual spring attachment pegs
    [aeropress_cleaner.scad]
2026-06-06 fix: Correct wall slot quadrant (bottom-left) and shorten wiper arm to 35mm to reach center only
    [aeropress_cleaner.scad]
2026-06-06 feat: Extend wiper arm to 65mm to completely cross plunger face, widen slot to 230 degrees, and adjust spring post to [-55, -12] to prevent over-center lock
    [aeropress_cleaner.scad]
2026-06-06 fix: Make ring 35mm tall to contain stop ledge inside, widen wall slot to 330 degrees to cover full sweep range
    [aeropress_cleaner.scad]
2026-06-06 fix: Reorder CSG tree and simplify slot to solid wedge to fix rendering artifacts inside the ring
    [aeropress_cleaner.scad]
2026-06-06 fix: Define slot cutout as difference of cylinder and convex wedge to fix triangulation spikes inside ring
    [aeropress_cleaner.scad]
2026-06-06 fix: Offset center vertex in slot sector polygon to prevent boolean singularities and rendering spikes
    [aeropress_cleaner.scad]
2026-06-06 chore: Disable manifold in frame render loop, slow down camera spin to 90 degrees, and double frame delay to slow down animation speed
2026-06-06 fix: Replace multi-cylinder stop ledge with a single rotate_extrude polygon to eliminate visual triangulation artifacts
    [aeropress_cleaner.scad]
2026-06-06 fix: Increase slot height to 10mm to clear blade, shift blade start to x=8mm to clear pivot knuckle, and nest CSG to protect knuckles from the taller slot
    [aeropress_cleaner.scad]
2026-06-06 feat: Convert pivot to use standard M3 metal screw instead of printed pin, update STL export list
    [aeropress_cleaner.scad]
2026-06-06 docs: Update resurrection plan with final M3 pivot, 10mm wall slot, linear spring pegs, and assembly steps
2026-06-06 feat: Add Metal Filter Cleaner (AMFC) SCAD model, refactor export script for both projects, and document both tools in README
    [filter_cleaner.scad]
2026-06-06 docs: Update resurrection plan with Metal Filter Cleaner details
2026-06-06 feat: Replace small grip tab with larger, full-height rounded ergonomic grip wing
    [aeropress_cleaner.scad]
2026-06-06 feat: Relocate ergonomic grip wing to the left side (near pivot) to allow comfortable one-handed squeeze operation
    [aeropress_cleaner.scad]
2026-06-06 feat: Add parameter for left-handed mirrored layout and default to true
    [aeropress_cleaner.scad]
2026-06-06 feat: Replace grip wing with a spacious 20mm finger loop handle for a secure wrapped mechanical grip
    [aeropress_cleaner.scad]
2026-06-06 feat: Move grip loop to bottom-left quadrant to enable natural one-handed trigger squeeze without collisions, and ensure solid loop side walls
    [aeropress_cleaner.scad]
2026-06-06 feat: Rename left_handed to right_handed and invert default to false, restoring left-side geometry for natural left-handed grip
    [aeropress_cleaner.scad]
2026-06-06 fix: Solve knuckle disconnection, horizontal grip orientation, and lever clipping
    [aeropress_cleaner.scad]
2026-06-06 feat: Implement 2-pivot geared mechanism (ice cream scoop squeeze) with large printable gear teeth sectors
    [aeropress_cleaner.scad]
2026-06-07 feat: Redesign handle to be a U-channel nesting shell (ice cream scoop) that encloses the trigger lever and spring
    [aeropress_cleaner.scad]
2026-06-07 feat: Redesign handle to be a vertical cylindrical grip with a top-mounted thumb disher trigger lever
    [aeropress_cleaner.scad]
2026-06-07 feat: Align handle, pivots, and casing symmetrically along the Y=0 axis for true inline ice cream scoop (disher) geometry
    [aeropress_cleaner.scad]
2026-06-07 feat: Implement a solid horizontal inline bar handle (D=22, length=60) that prints support-free using vertical extrusion
    [aeropress_cleaner.scad]
2026-06-07 feat: Redesign handle to be a thin round horizontal cylinder (D=20, Z=-25) offset below the trigger for a true disher scoop shape
    [aeropress_cleaner.scad]
2026-06-07 feat: Cut 120-degree sector on the right side of the wiper ring to create a C-shaped snap collar, allowing side-entry snap mounting
    [aeropress_cleaner.scad]
2026-06-07 feat: Optimize gear sector rendering to use wedge segment slices instead of full circular discs, reducing material use
    [aeropress_cleaner.scad]
2026-06-07 feat: Restore wiper ring to a full closed 360-degree circle for maximum structural integrity
    [aeropress_cleaner.scad]
2026-06-07 feat: Shift pivot B leftwards to X=-80.0 to implement a 4:1 gear ratio, enabling a full 180-degree wiper sweep from a 45-degree trigger squeeze
    [aeropress_cleaner.scad]
2026-06-07 fix: Shorten wiper arm to 63mm to prevent ring wall clipping; re-align spring pegs to X=-65.0, Y=10.0 to implement a true compression spring setup
    [aeropress_cleaner.scad]
2026-06-07 fix: Shift ring wall slot sector to 15-345 degrees, moving the solid bridge column to the far right to prevent wiper arm clipping during rotation
    [aeropress_cleaner.scad]
2026-06-07 feat: Redesign handle and casing into a unified inline horizontal paddle (Z=-12 to +12) enclosing the gear sectors and spring, held by two vertical M3 screws
    [aeropress_cleaner.scad]
2026-06-07 fix: Use 2D square() instead of 3D cube() inside linear_extrude to fix gear pocket cutout warning
    [aeropress_cleaner.scad]
2026-06-07 fix: Reverse animation kinetics so that squeezing pulls the trigger lever back counter-clockwise and sweeps the wiper arm clockwise
    [aeropress_cleaner.scad]
2026-06-07 fix: Align wiper to park at +90 degrees and sweep clockwise to -90 degrees, so it scrapes the right half (chamber face) while keeping the pull-back trigger squeeze
    [aeropress_cleaner.scad]
2026-06-07 style: Color the return spring red to highlight it as an off-the-shelf component; lift the thumb trigger tab by 1.5mm for smoother deck clearance
    [aeropress_cleaner.scad]
2026-06-07 fix: Redesign integrated casing to be bulbous (D=80) around the large 36mm sector gear and narrow (D=20) at the handle grip, enclosing the gears completely to prevent clipping
    [aeropress_cleaner.scad]
2026-06-07 fix: Close translate block properly and add curved riser slot cutout through the top casing plate to allow gooseneck trigger rotation
    [aeropress_cleaner.scad]
2026-06-07 fix: Shift the plunger ring wall slot up to Z=-5 to +7 to clear the wiper blade, and center the mock spring at Z=0 to prevent clipping the gearbox bottom deck
    [aeropress_cleaner.scad]
2026-06-07 fix: Shift wiper and trigger assembly translations to Z=0.0 to match the new inline horizontal flat paddle casing, and increase M3 screw lengths to 24mm
    [aeropress_cleaner.scad]
2026-06-07 feat: Scale down the gearbox for a highly compact design: Pivot B = -60.0, Gear B = 20mm, Gear A = 5mm, reducing the bulbous housing width from 80mm to 46mm
    [aeropress_cleaner.scad]
2026-06-07 feat: Redesign handle into a simple open flat bar (Z=-12 to -4) with exposed gears and spring on top, completely eliminating the gearbox casing and gooseneck riser
    [aeropress_cleaner.scad]
2026-06-07 feat: Restructure handle into a straight tuning-fork clevis shape (split into top/bottom forks) sandwiching the gears and spring vertically, with open sides to clear the gear sweep
    [aeropress_cleaner.scad]
2026-06-07 fix: Align trigger riser radius from 25mm to 12mm to match the 12mm guide slot cutout in the top plate, fixing riser alignment
    [aeropress_cleaner.scad]
2026-06-07 fix: Expand trigger guide slot angular limits to 60-165 degrees and add 0.5mm radial clearance to resolve riser cylinder clipping at sweep limits
    [aeropress_cleaner.scad]
2026-06-07 fix: Extend trigger guide slot to 180 degrees to guarantee zero clipping at fully squeezed limit
    [aeropress_cleaner.scad]
2026-06-07 fix: Elevate thumb tab bottom to Z=13.0 and remove center=true to resolve vertical clipping/z-fighting with the top plate
    [aeropress_cleaner.scad]
2026-06-07 fix: Relocate stationary spring peg to [-85.0, 0.0] to resolve vertical collision with Sector B, converting return action to compression spring
    [aeropress_cleaner.scad]
2026-06-07 fix: Add a spring clearance slot to the handle top plate to prevent the return spring from clipping the slot outer corner during compression
    [aeropress_cleaner.scad]
2026-06-07 fix: Expand internal gear pocket to 30mm width, opening the handle sides (tuning-fork clevis) and resolving the trigger arm body collision
    [aeropress_cleaner.scad]
2026-06-07 fix: Widen top riser slot and shrink spring/pegs to 5mm/3mm to resolve top-plate corner binding and spring-knuckle collision
    [aeropress_cleaner.scad]
2026-06-08 fix: Lengthen handle casing to -145mm and extend clevis slot left to -120mm to allow full trigger travel to clean the plunger
    [aeropress_cleaner.scad]
2026-06-08 feat: Redesign filter cleaner to 4-layer sandwich using Flex PLA inserts with integrated dados and scraping ridges
    [filter_cleaner.scad]
2026-06-08 feat: Separate Flex PLA blades into flat and grooved versions for single-dado sandwich model
    [filter_cleaner.scad]
2026-06-08 fix: Revert to symmetric flex plates with 0.15mm dado depth each, and fix back plate screw tap hole alignment
    [filter_cleaner.scad]
2026-06-08 fix: Add M3 square nut pockets to the back rigid plate, change back holes to clearance, and correct mock screw rendering direction
    [filter_cleaner.scad]
2026-06-08 fix: Redesign M3 square nut pockets to captive horizontal slots in the sides of the back rigid plate
    [filter_cleaner.scad]
2026-06-08 fix: Replace captive slots with recessed hex nut pockets on the back face of the back rigid plate
    [filter_cleaner.scad]
2026-06-08 feat: make plunger handle thicker and add dovetail wiper [rel: v1.1.0]
    [aeropress_cleaner.scad]
2026-06-08 fix: restore spring post and use hex nuts for pivots [rel: v1.1.1]
    [aeropress_cleaner.scad]
2026-06-09 fix: shift trigger to clear thicker handle and add overlaps for volumes [rel: v1.1.2]
    [aeropress_cleaner.scad]
2026-06-09 fix: invert bolt direction, head on top, nut on bottom [rel: v1.1.3]
    [aeropress_cleaner.scad]
2026-06-10 Refactor gears and improve printability of Aeropress cleaner
    - Refactored gear sector to use MCAD involute gears for smoother meshing.
    - Aligned wiper arm, gear, and blade slot to the bottom of the knuckle (Z=-3.6) to improve printability.
    - Aligned trigger gear to bottom to mesh with new wiper position.
    - Added 2mm roundover to the handle casing edges.
    - Updated export script to render animations with 2 full camera rotations.
    - Added workspace rule to always render and show preview GIF on model updates.
    [aeropress_cleaner.scad, blade.stl, filter_back.stl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]
2026-06-10 Remove obsolete pin.stl
    [pin.stl]
2026-06-10 Update export.ps1 to 720-deg camera rotation and regenerate files [rel: v1.2.1]
    [blade.stl, filter_back.stl, filter_blade.stl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]
2026-06-10 Use stable OpenSCAD in workflow, restore STLs, and regenerate GIFs [rel: v1.2.2]
    [blade.stl, filter_back.stl, filter_blade.stl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]
2026-06-10 Add individual part PNG rendering to export scripts and regenerate files [rel: v1.2.3]
    [filter_back.stl, filter_front.stl, ring.stl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]
2026-06-10 Vendor MCAD involute_gears.scad and fix assign() for nightly compatibility [rel: v1.2.7]
    [blade.stl, filter_back.stl, filter_blade.stl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]
2026-06-10 Fix gear pitch calculation for official MCAD library and regenerate all files [rel: v1.2.8]
    [aeropress_cleaner.scad, filter_back.stl, filter_blade.stl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]
2026-06-10 Split wiper pivot knuckle to prevent burying gear teeth and resolve collision [rel: v1.2.9]
    [aeropress_cleaner.scad, blade.stl, filter_back.stl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]
2026-06-10 Refactor trigger arm and wiper dovetail [rel: v1.3.0]
    - Wiper dovetail slot and blade base height reduced to 3.6mm to make the attachment flush.
    - Trigger arm shifted down to Z=-3.6 -> 0.0 to allow printing flat on the bed.
    - Trigger spring peg kept pointing DOWN but moved to Z=-3.6 -> -6.6 to avoid collision with gooseneck riser.
    - Casing pocket extension split and deepened to Z=-7.1 to clear the downward trigger peg, and stationary post lengthened to match.
    - Trigger arm end and riser shifted to X=-11.8 to ensure 0.2mm overlap and resolve non-manifold line-contact warning.
    - Previews and STLs will be auto-generated by GitHub Action.
    [aeropress_cleaner.scad]
2026-06-10 Revert trigger offset to original printable design [rel: v1.3.1]
    - Reverted trigger arm back to Z=0.0 -> 3.6 (offset).
    - Reverted spring peg back to Z=0.0 -> -3.0 (pointing down from arm).
    - Knuckle and gear bottoms sit flat on the bed (Z=-3.6), peg tip is 0.6mm off the bed (Z=-3.0), preventing it from lifting the part.
    - Reverted casing pocket back to Z=-4.1 -> 4.1.
    - Reverted stationary casing post to start at Z=-5.0 (height 7.0).
    [aeropress_cleaner.scad]
2026-06-10 Replace fragile body spring peg with M3 screw hole [rel: v1.3.2]
    - Removed printed stationary spring post from ring_body.
    - Added d=2.8mm thread hole (depth 17.9mm, Z=-15.0 to 2.9) for self-tapping M3 screw.
    - Added d=6.0mm counterbore (depth 3.0mm) at the bottom of the handle to keep the screw head flush.
    [aeropress_cleaner.scad]
2026-06-11 Increase plunger diameter and restore trigger gear sector angle [rel: v1.3.3]
    - Increased plunger_di from 57.2 to 58.0 to fit 58mm plunger.
    - Restored trigger gear sector_angle from 60 to 75 degrees (5 teeth) to prevent disengagement under full travel.
    [aeropress_cleaner.scad]
2026-06-11 Improve filter cleaner ergonomics, tolerances, and entry guide [rel: v1.4.0]
    - Replaced vertical corner rounding with 3D rounded box (2mm radius) for all-edge roundover on rigid frame halves.
    - Extended TPU flex plate by 3mm only at the top and tapered it to form a sloped V-mouth entry funnel (removes blocky ears, bottom remains flush).
    - Fixed a bug in the entry funnel rotation that prevented it from cutting the part.
    - Increased screw clearance hole diameter to 3.5mm for easier assembly.
    - Reduced hex nut pocket width to 5.8mm for a snug, non-spinning fit.
    - Widened frame to 80mm to maintain wall thickness around screw holes with the new rounded edges.
    - Increased frame thickness to 6mm to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
    [filter_cleaner.scad]
2026-06-12 Secure spring screws with nuts and add wiper slot floor [rel: v1.4.1]
    - Casing spring screw hole converted to clearance (d=3.4mm) with a 3.0mm deep hex nut pocket (d=5.8mm flat-to-flat) in the pocket floor to secure the screw with a nut.
    - Wiper dovetail slot height reduced from 3.6mm to 2.6mm, leaving a 1.0mm solid floor at the bottom of the arm for printability and strength.
    - Wiper blade base height scaled to 2.6mm to match the shallower slot.
    - Trigger spring peg replaced with a 20mm M3 screw passing through the gooseneck riser, secured with an M3 nut in a recess at the bottom of the trigger arm (Z=0.0).
    - Added mock screws in assembly to verify alignment.
    [aeropress_cleaner.scad]
2026-06-12 Remove stop ledge, add guide bumps, and optimize handle casing [rel: v1.4.2]
    - Removed stop ledge at Z=15..18 and extended upper chamber bore to the top (Z=20) to allow correct plunger insertion.
    - Added 4 guide bumps (0.8mm protrusion) inside the bore at Z=8.0 to prevent plunger tipping.
    - Shrunk internal gear pocket height from 8.2mm to 7.6mm (Z=-3.8 to 3.8) to reduce vertical play and arm sag.
    - Shortened spring pocket extension to end at X=-95 (leaving handle solid from -95 to -145 for strength).
    - Removed top spring clearance slot to keep handle top solid (spring/nut to be inserted from bore).
    - Adjusted casing nut pocket Z level and trigger riser slot to match the new pocket height.
    [aeropress_cleaner.scad]
2026-06-12 Stiffen wiper arm to 6.6mm height and deepen slot to 4.6mm [rel: v1.4.3]
    - Increased wiper arm bar thickness from 3.6mm to 6.6mm (Z = -3.6 to 3.0) to increase bending stiffness by ~6x and prevent print warping/sagging.
    - Deepened dovetail slot from 2.6mm to 4.6mm (Z = -1.6 to 3.0), leaving a robust 2.0mm solid floor at the bottom of the arm.
    - Thickened wiper blade base to 4.6mm to match, and translated flap to keep it sticking out 3.0mm above the arm (reaching Z=6.0).
    [aeropress_cleaner.scad]
2026-06-12 Fix mock screw alignments and shorten gear pocket extension [rel: v1.4.4]
    - Fixed mock_m3_screw definition to have flush head Z=0 and correct length.
    - Adjusted all mock screw Z translations in assembly() to sit flush in their counterbores.
    - Changed casing spring screw to M3x16 so it pokes into the pocket by 4.8mm to act as peg.
    - Shortened the gear pocket extension by another 5mm (ends at X=-90) to increase handle thickness/strength.
    [aeropress_cleaner.scad]
2026-06-12 Make gear pocket extension asymmetric to thicken bottom handle wall [rel: v1.4.5]
    - Changed pocket extension from symmetric Y=-15..15 to asymmetric Y=-5..15 (X=-90 to -50).
    - This keeps the bottom wall of the handle (Y < 0, X < -60) solid, increasing thickness from 5mm to 15mm for significantly higher strength.
    - The pocket still fully clears the spring and trigger riser which are in Y > 0.
    [aeropress_cleaner.scad]
2026-06-12 Tighten trigger riser slot to match actual travel [rel: v1.4.6]
    - Shrunk the trigger riser slot in the top plate from a 120-degree arc (60..180) to a 60-degree arc (85..145).
    - This matches the actual travel of the trigger (90 relaxed to 135 pulled), closing unnecessary openings and protecting the spring/internals.
    [aeropress_cleaner.scad]
2026-06-12 Support 10mm OD spring and change casing peg to M3x30 through-screw [rel: v1.4.7]
    - Changed casing spring peg screw (X=-85) to a through-screw (M3x30) with top counterbore and bottom hex nut pocket, matching pivot screws.
    - Increased internal handle pocket height from 7.6mm to 11.0mm (Z=-5.5..5.5) to clear the 10mm OD spring.
    - Widened pocket extension to Y=-7..15 to provide 2mm clearance for 10mm spring.
    - Adjusted trigger riser slot start Z to 5.5 (height 9.6) and ring wall slot to Z=-5.5..7.0 (height 12.5) to align with new pocket.
    - Updated mock spring in assembly to d=10.0 and centered it at Z=0.
    [aeropress_cleaner.scad]
2026-06-12 Fix spring clipping with trigger arm by thinning riser base and arm end [rel: v1.4.8]
    - Thinned trigger arm end to d=7.0 (Z=0..3.6).
    - Split and thinned riser base to d=7.0 (Z=3.5..5.0) to clear 10mm OD spring (ID 8.0) centered at Z=0.
    - Keeps upper riser at d=10.0 for strength.
    [aeropress_cleaner.scad]
